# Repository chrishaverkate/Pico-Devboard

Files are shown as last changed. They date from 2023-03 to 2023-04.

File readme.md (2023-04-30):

# Pico Devboard - v1.0.0
A very simple and generic development board for a Raspberry Pi Pico that leverages another Pico as a programmer and debugger. The development board is designed to make it simple and cheap to start programming on the Raspberry Pi Pico

**Fabrication Preview**

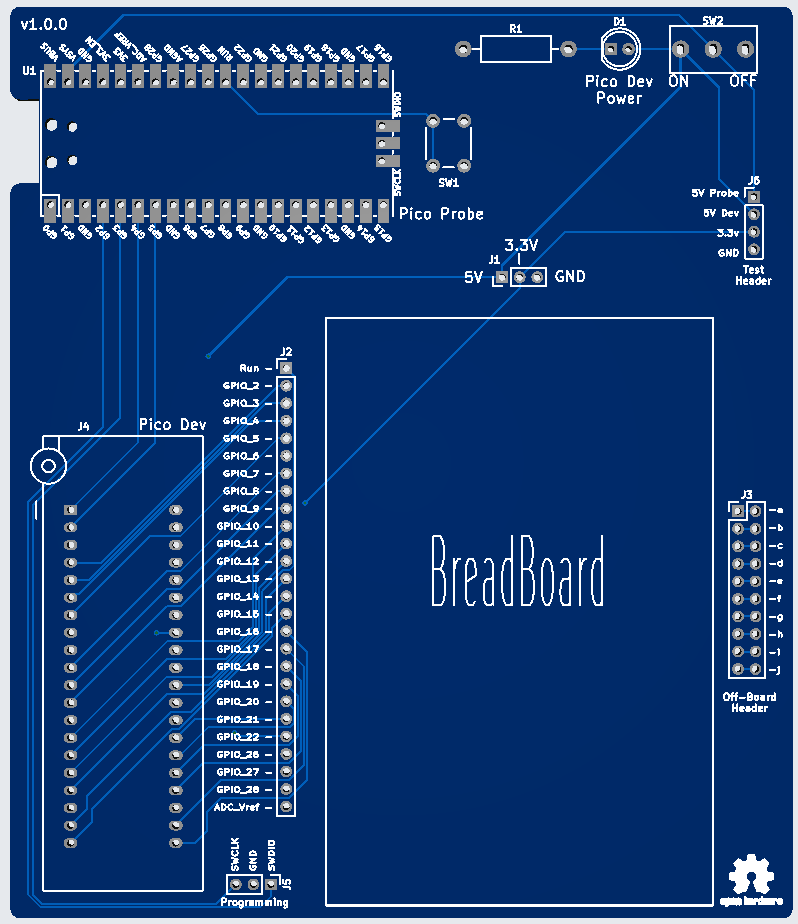
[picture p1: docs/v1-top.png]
v1 top view


# Primary Features
* Pico soldered in as a [Pico Probe](https://github.com/raspberrypi/picoprobe)
* [ZIF](https://en.wikipedia.org/wiki/Zero_insertion_force) socket for holding the Pico being developed
* Room for small breadboard
* GPIO, Power, GND, and expansion header located by breadboard
* Probe points for power and ground
* Pico Dev board power switch

# Bill of Materials
*details coming*
* 2x [Raspberry Pi Pico](https://www.pishop.us/product/raspberry-pi-pico/) (U1 and in J4)
* [ZIF socket](https://www.adafruit.com/product/383) (J4)
* [Headers](https://a.co/d/4zF3gvf) (all 2.54mm pitch)
	* 1x - 1x26 GPIO (J2)
	* 2x - 1x3  power and programming (J1 and J5)
	* 1x - 2x10 off-board expansion (J3)
	* 1x - 1x4  test pins (J6)
* [Test Pins](https://a.co/d/6bz0lk5) (J6)
* [Slide switch](https://a.co/d/a2dGuMf) (SW2)
* [Push button](https://a.co/d/cavYAee) (SW1)
* LED (D1)
* Resistor (R1)
* [Breadboard](https://a.co/d/gGRnvQ6)
* [Rubber Standoffs](https://a.co/d/2oCXgiC)

# Ordering
I used [JLCPCB](https://jlcpcb.com) and could buy 10 boards for just under $16.

# Software
See the [Software Readme](software/pico-demo/readme.md)

# Resources
Need to collect links to helpful docs

# Errata
## 1) Serial RX/TX Flipped
**Description**: Serial RX/TX lines flipped from Pico Probe (U1) to Pico Dev (J4).
**Symptom if Uncorrected**: Serial communication will not work.
**Mitigation**:
1. Cut traces, on top of board, coming from U1 pins GP4 and GP5
2. Solder wires, on bottom of board:
	* U1 pin GP4 to J4 pin 2
	* U1 pin GP5 to J4 pin 1

## 2) J5 Silk Screen Misslabelled
**Description**: The labels for SWCLK and SWDIO on J5 are swapped.
**Symptom if Uncorrected**: Programming will fail with an error about the pico not responding.
**Mitigation**: Make correction when wiring

# Future Features
* Move or duplicate J2 to the right side of the breadboard
  * This will make it easier to connect GPIO directly to the off-board expansion header (J3)
* Add 2-pin jumper on 5V trace, between power switch (SW2) and power header (J1)
  * When the jumper is removed the power will be disconnected, allowing for in-line power measurement 

# Images

**Building**
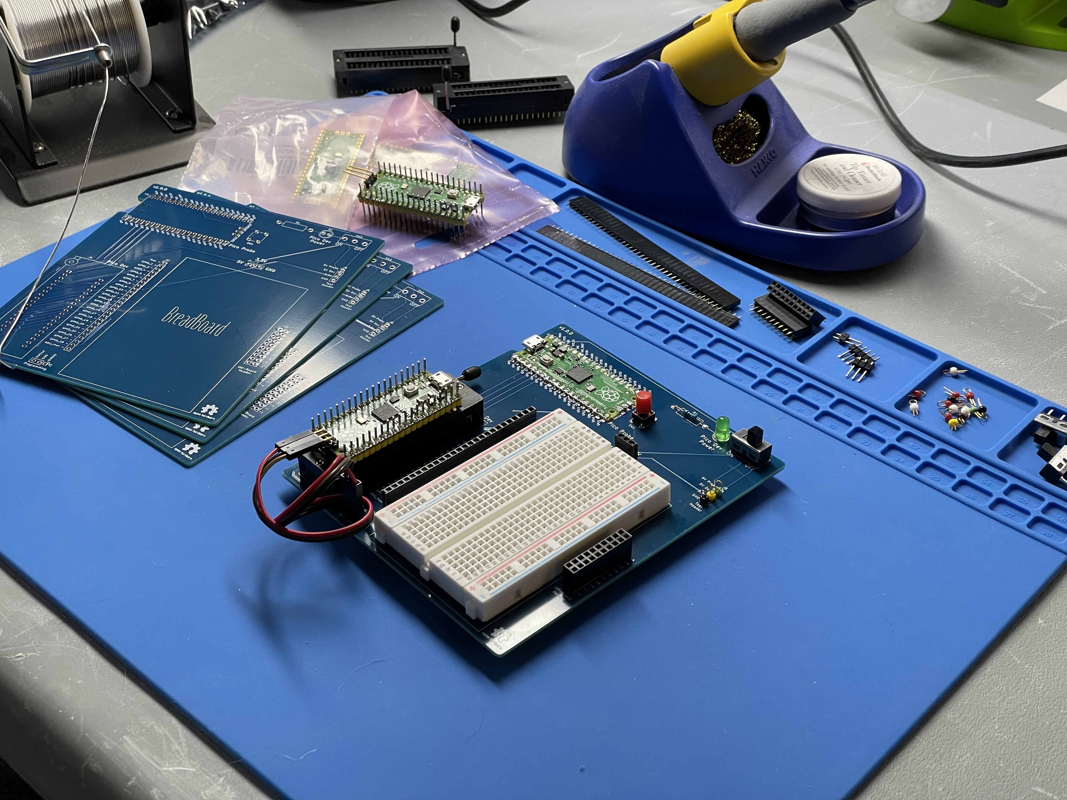
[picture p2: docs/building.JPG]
Building


**Built**
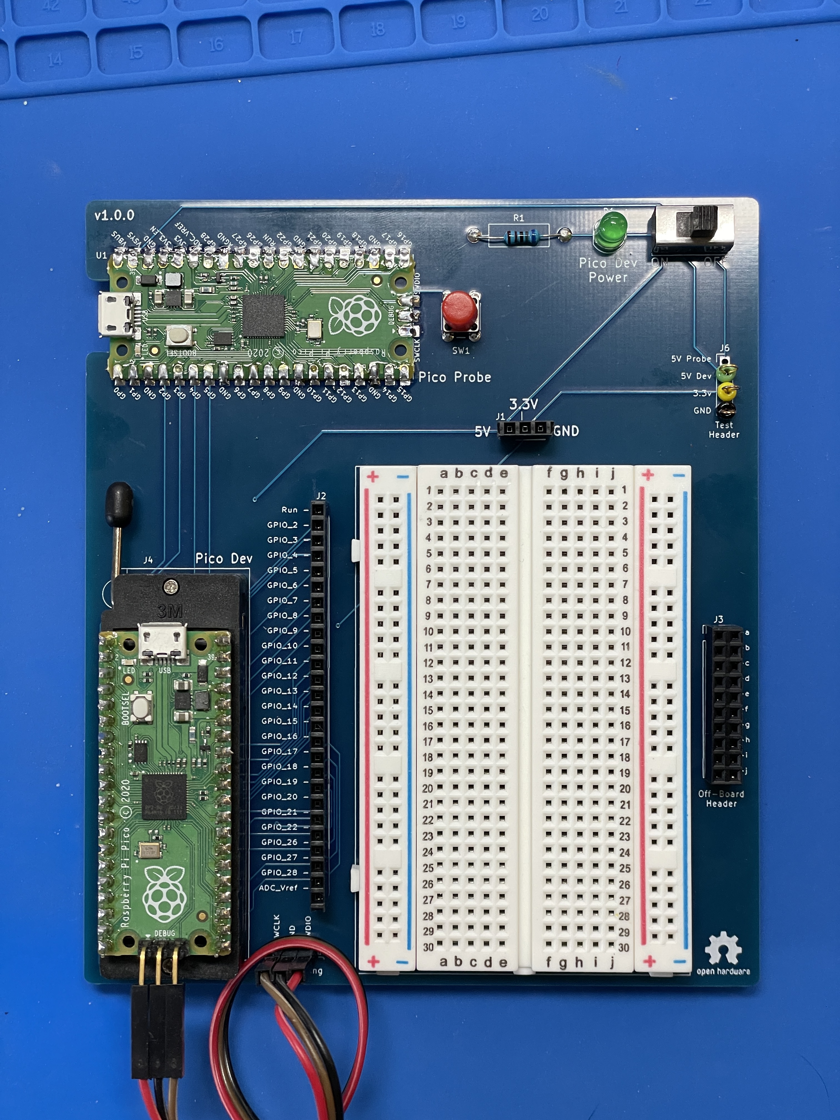
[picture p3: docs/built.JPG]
Built


**Alive!**
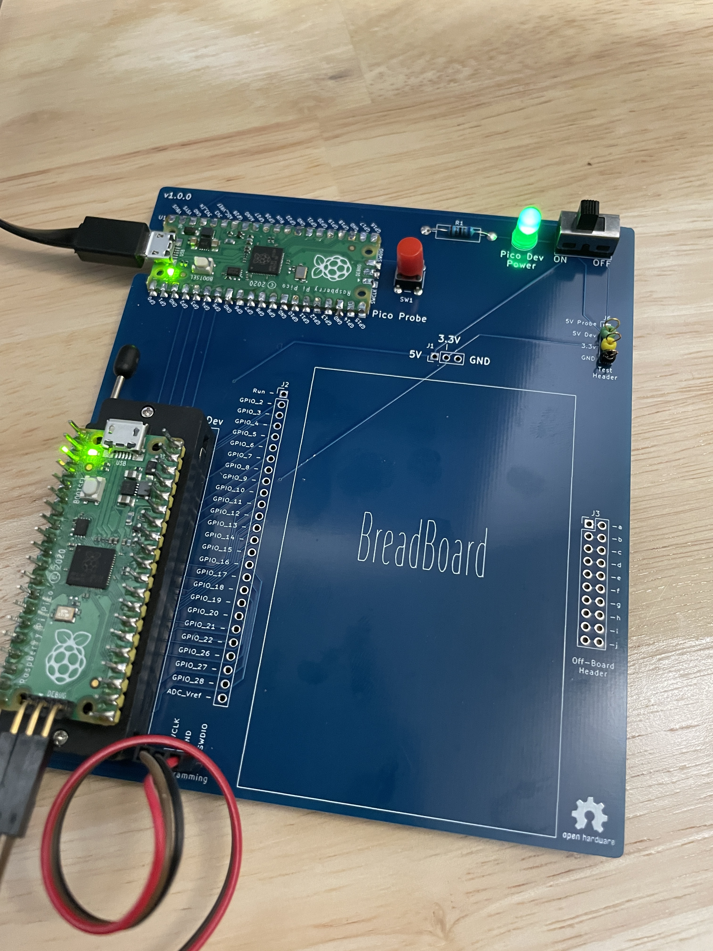
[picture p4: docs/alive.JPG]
Alive


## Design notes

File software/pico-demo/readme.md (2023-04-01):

# Overview
A template for getting started with the Raspberry Pi Pico. 

This is a limited guide and assumes familiarity with:
* CMake
* C/C++
* Docker
* Raspberry Pi Pico

To learn more, there are plenty of guides, tutorials, and videos that do a much better
job than I can today.

## Features
* CMake build system
* CMake toolchain file for cross-compiling
* Docker container for cross-compiling
* Abstraction library to enable TDD on core logic
* Google Tests and Google Benchmark libraries setup with example
* A Pico related documents to get started

## Getting Started
This project is just a starting template and only tested on Linux. 
It's likely usable in WSL and on Mac (with some modification), but I haven't tested it.

_Note_, normally I would include documents in the 'docs' folder. Since this software project
is nested in a larger repo, they can be found in the root docs folder.

### Prerequisites
* [Docker](https://docs.docker.com/get-docker/)
* [Pico Probe](https://www.raspberrypi.org/documentation/rp2040/getting-started/#debug-probe)
* [Raspberry Pi Pico](https://www.raspberrypi.org/products/raspberry-pi-pico/)
* [CMake](https://cmake.org/download/)
* Compiler tools for your platform

### Build - Local
To build locally, use the convenience script [run-build-linux.bash](scripts/run-build-linux.bash).
You can see the details of the build for setting up an IDE for more interactive development.
```bash
cd scripts && ./run-build-linux.bash linux
```

### Build - Docker
Again, there is a convenience script [run-build-docker.bash](scripts/run-build-docker.bash).
```bash
cd scripts && ./run-build-docker.bash
```

The benefit to this script is the output will be placed in the 'bin' folder,
and it will be ready to flash to the Pico.

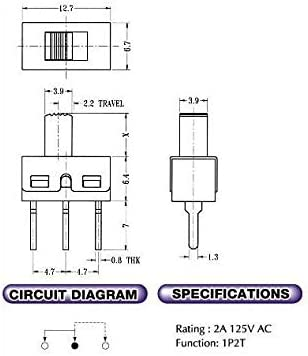
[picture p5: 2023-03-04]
docs/switch-diagram.png

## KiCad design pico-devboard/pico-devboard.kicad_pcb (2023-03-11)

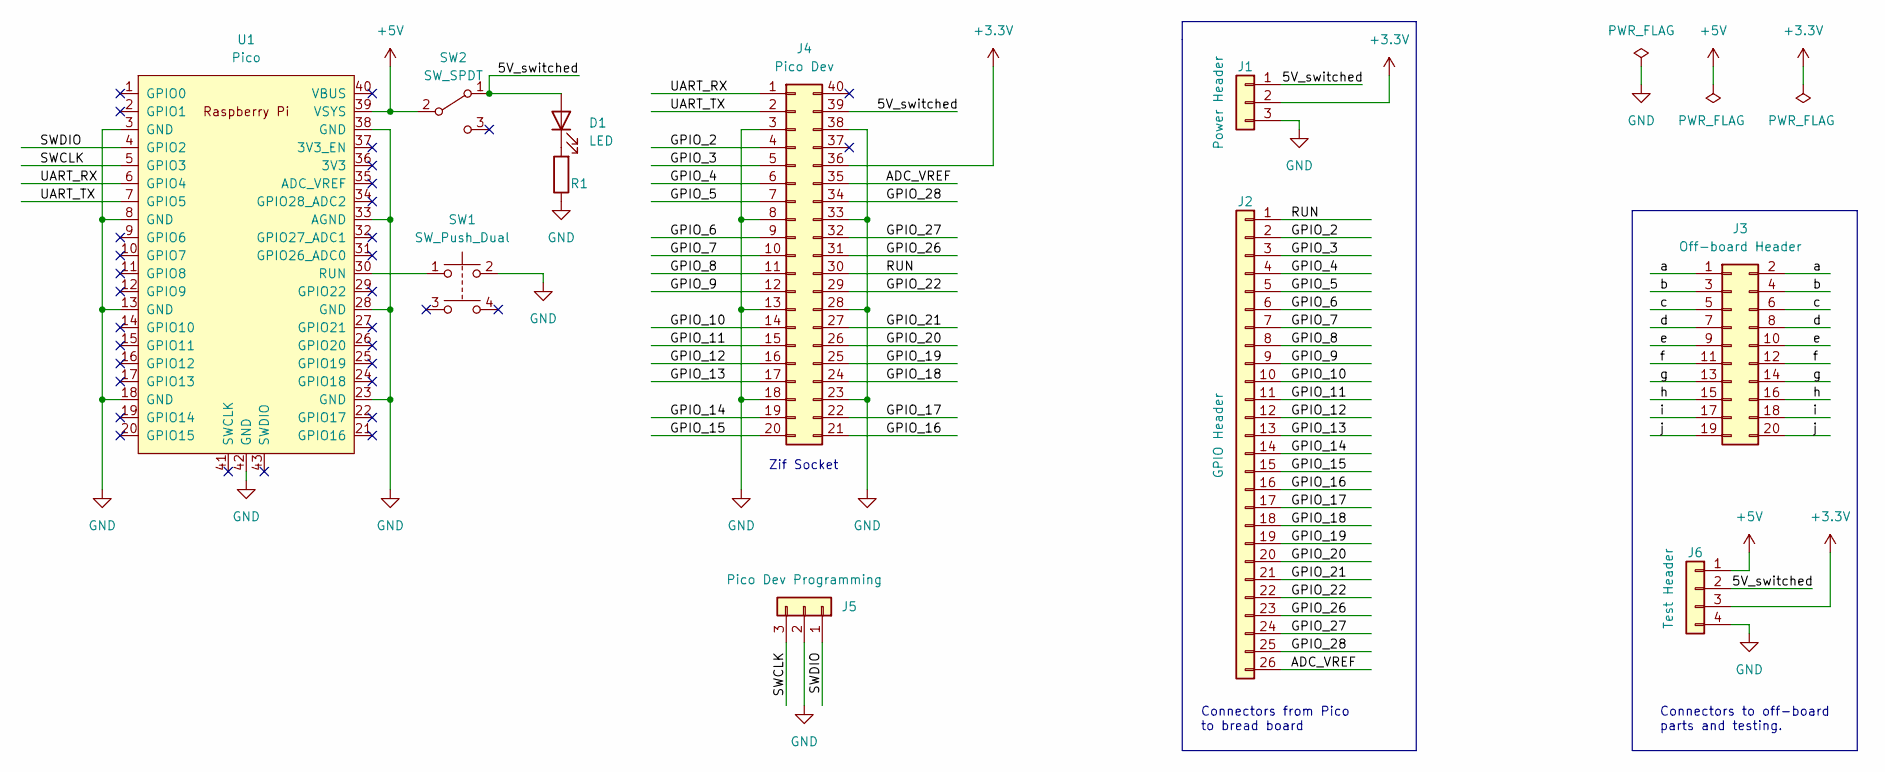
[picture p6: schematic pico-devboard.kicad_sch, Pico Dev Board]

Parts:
D1: LED; LED_D5.0mm
J1: Power Header; PinHeader_1x03_P2.54mm_Vertical
J2: GPIO Header; PinHeader_1x26_P2.54mm_Vertical
J3: Off-board Header; PinHeader_2x10_P2.54mm_Vertical
J4: Pico Dev; DIP_Socket-40_W11.9_W12.7_W15.24_W17.78_W18.5_3M_240-1280-0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
J5: Pico Dev Programming; PinHeader_1x03_P2.54mm_Vertical
J6: Test Header; PinHeader_1x04_P2.54mm_Vertical
R1: R; R_Axial_DIN0411_L9.9mm_D3.6mm_P15.24mm_Horizontal
SW1: SW_Push_Dual; SW_PUSH_6mm_H8mm
SW2: SW_SPDT; sw_slide_vert_SPDT
U1: Pico; RPi_Pico_SMD_TH

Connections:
+3V3: J1.2, J4.36, J6.3
+5V: J6.1, SW2.2 (B), U1.39 (VSYS)
/5V_switched: D1.2 (A), J1.1, J4.39, J6.2, SW2.1 (A)
/ADC_VREF: J2.26, J4.35
/GPIO_2: J2.2, J4.4
/GPIO_3: J2.3, J4.5
/GPIO_4: J2.4, J4.6
/GPIO_5: J2.5, J4.7
/GPIO_6: J2.6, J4.9
/GPIO_7: J2.7, J4.10
/GPIO_8: J2.8, J4.11
/GPIO_9: J2.9, J4.12
/GPIO_10: J2.10, J4.14
/GPIO_11: J2.11, J4.15
/GPIO_12: J2.12, J4.16
/GPIO_13: J2.13, J4.17
/GPIO_14: J2.14, J4.19
/GPIO_15: J2.15, J4.20
/GPIO_16: J2.16, J4.21
/GPIO_17: J2.17, J4.22
/GPIO_18: J2.18, J4.24
/GPIO_19: J2.19, J4.25
/GPIO_20: J2.20, J4.26
/GPIO_21: J2.21, J4.27
/GPIO_22: J2.22, J4.29
/GPIO_26: J2.23, J4.31
/GPIO_27: J2.24, J4.32
/GPIO_28: J2.25, J4.34
/RUN: J2.1, J4.30
/SWCLK: J5.3, U1.5 (GPIO3)
/SWDIO: J5.1, U1.4 (GPIO2)
/UART_RX: J4.1, U1.6 (GPIO4)
/UART_TX: J4.2, U1.7 (GPIO5)
/a: J3.1, J3.2
/b: J3.3, J3.4
/c: J3.5, J3.6
/d: J3.7, J3.8
/e: J3.9, J3.10
/f: J3.11, J3.12
/g: J3.13, J3.14
/h: J3.15, J3.16
/i: J3.17, J3.18
/j: J3.19, J3.20
GND: J1.3, J4.3, J4.8, J4.13, J4.18, J4.23, J4.28, J4.33, J4.38, J5.2, J6.4, R1.1, SW1.2, U1.3 (GND), U1.8 (GND), U1.13 (GND), U1.18 (GND), U1.23 (GND), U1.28 (GND), U1.33 (AGND), U1.38 (GND), U1.42 (GND)
unnamed: D1.1 (K), R1.2
unnamed: SW1.1, U1.30 (RUN)

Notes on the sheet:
Connectors from Pico to bread board
Connectors to off-board parts and testing.
Zif Socket

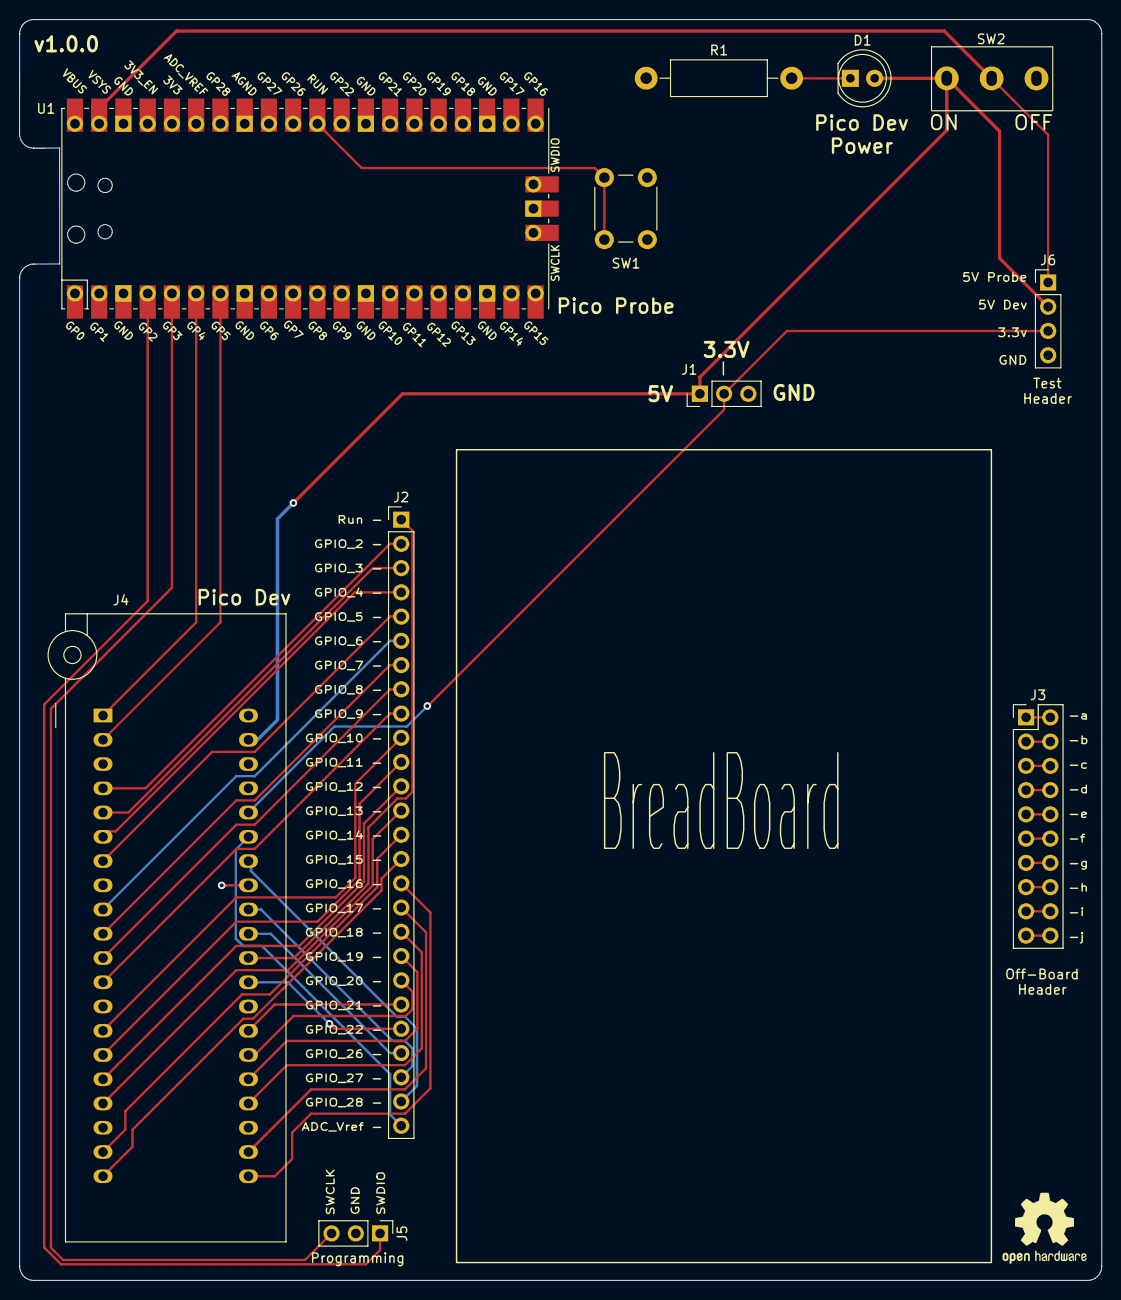
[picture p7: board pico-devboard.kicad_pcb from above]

Board: 2 copper layers, 113.4 x 132.1 mm, 11 parts (0 on the bottom side), 46 nets.

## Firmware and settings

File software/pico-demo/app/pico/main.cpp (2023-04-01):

#include <pico/binary_info.h>
#include <pico/stdlib.h>
#include <stdio.h>

#include "pin_assignments.h"

void onboard_led_heartbeat();
void init_io();

#pragma clang diagnostic push
#pragma ide diagnostic ignored "EndlessLoop"
int main (int argc, char** argv) {
	init_io();

	printf("\n\n--------------------------\n- Welcome to Pico\n--------------------------\n");

	uint64_t count = 0;
	printf("- Starting Main loop\n");
	while(true) {
		onboard_led_heartbeat();

		if (count++ % 10000000 == 0) {
			printf("Still alive! %llu\n", get_absolute_time());
		}
	}

	return 0;
}
#pragma clang diagnostic pop

void init_io() {
	stdio_init_all();
	gpio_init(Pins::OB_LED);
	gpio_set_dir(Pins::OB_LED, GPIO_OUT);

	printf("\n\n -> IO Initialized!\n");
}

void onboard_led_heartbeat() {
	static const uint64_t HB_PERIOD = 500000; // us
	static uint64_t last_time = 0;
	static bool state = false;

	const uint64_t now = get_absolute_time();

	if((now - last_time) > HB_PERIOD) {
		state = !state;
		last_time = now;
		gpio_put(Pins::OB_LED, state);
	}
}

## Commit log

2023-03-04 Finally starting git
    [pico-devboard-B_Cu.gbr, pico-devboard-B_Mask.gbr, pico-devboard-B_Paste.gbr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]
2023-03-05 Silkscreen, small adjustments, readme updates
    [pico-devboard.kicad_pcb, pico-devboard.kicad_sch]
2023-03-08 Fixing header spacing issue and re-routing
    [pico-devboard.dsn, pico-devboard.kicad_pcb, pico-devboard.kicad_sch]
2023-03-11 v1.0.0 fab files
    [pico-devboard-B_Cu.gbr, pico-devboard-B_Mask.gbr, pico-devboard-B_Paste.gbr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]
2023-04-30 Adding a couple ideas for next rev of board
